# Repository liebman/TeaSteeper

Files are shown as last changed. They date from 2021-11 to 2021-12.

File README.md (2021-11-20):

# TeaSteeper

TeaSteeper is a simple device to prevent tea from being over steeped.

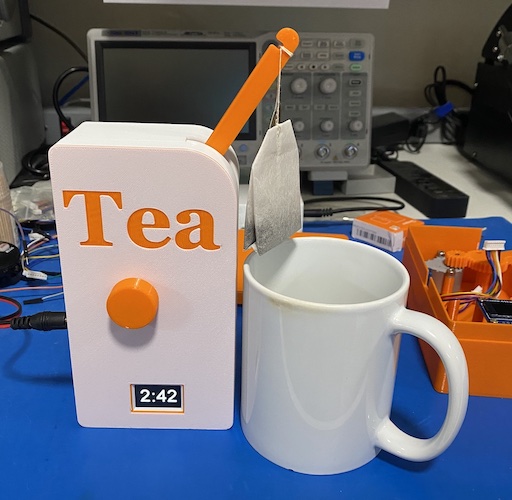
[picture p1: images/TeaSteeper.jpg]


- [src](src) contains firmware sources
- [kicad](kicad) contains [KiCad](https://www.kicad.org/) design files
- [enclosure](enclosure) contains [FreeCad](https://www.freecadweb.org/) and STL files for the enclosure.
These are designed for a FDM printer with a .4mm nozzle and .2mm layer height.

## Firmware

This project uses [PlatformIO](https://platformio.org/) to build firmware.

## Schematic

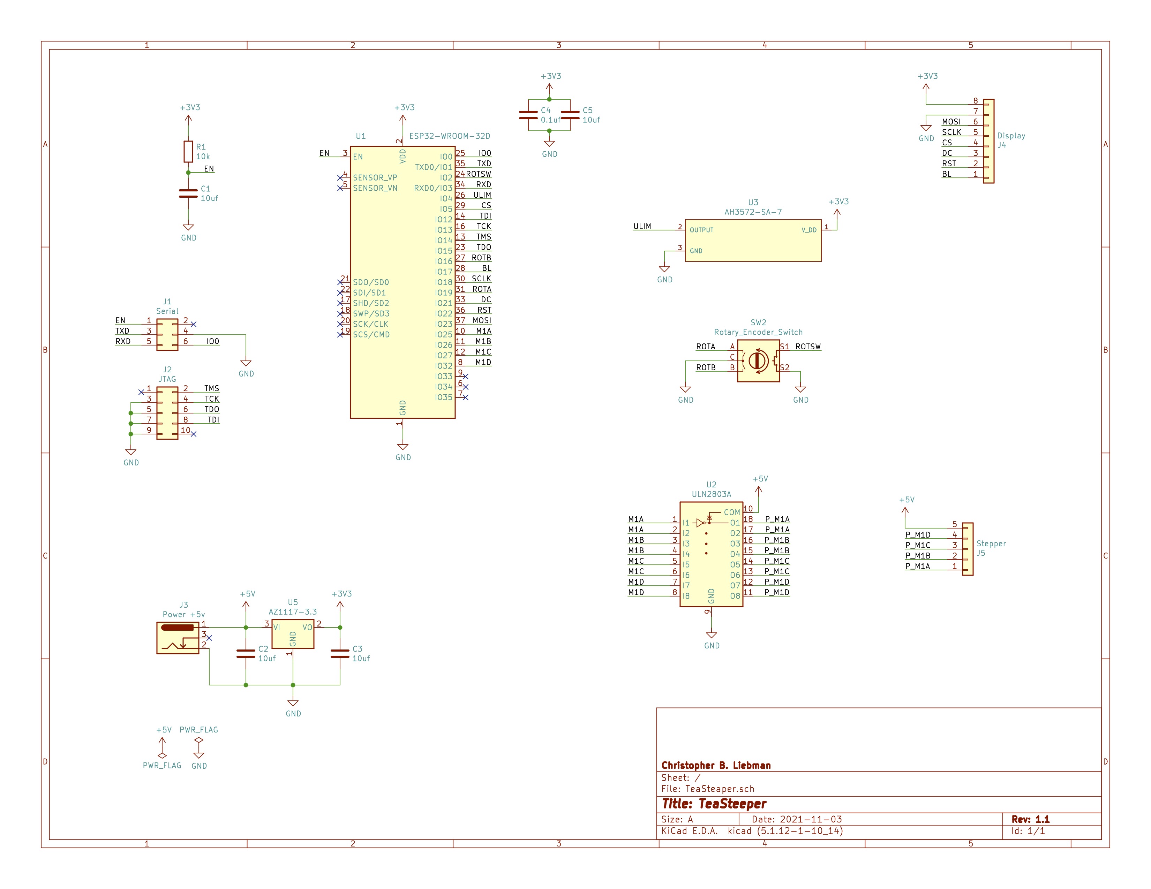
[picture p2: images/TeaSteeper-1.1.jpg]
Schematic


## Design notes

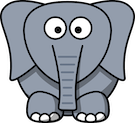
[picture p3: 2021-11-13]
src/elephant.png

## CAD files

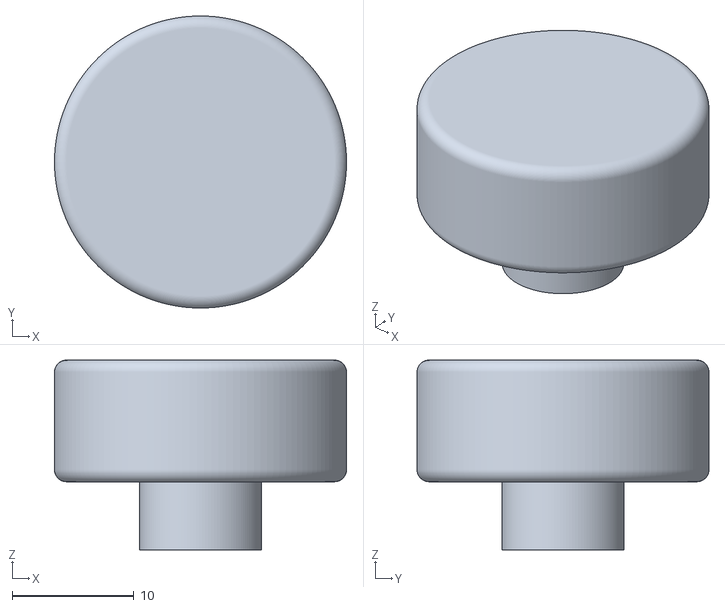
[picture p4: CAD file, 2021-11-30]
enclosure/assembly-AssemblyBody_knob.stl
24.0 x 24.0 x 15.6

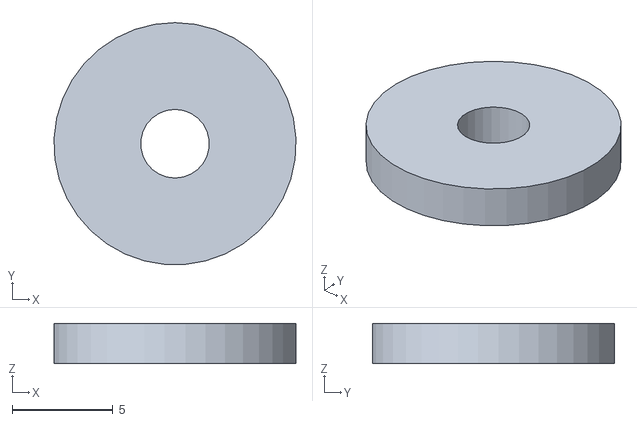
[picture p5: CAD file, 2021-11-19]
enclosure/assembly-AssemblyBody_gear02cap.stl
12.0 x 12.0 x 2.00

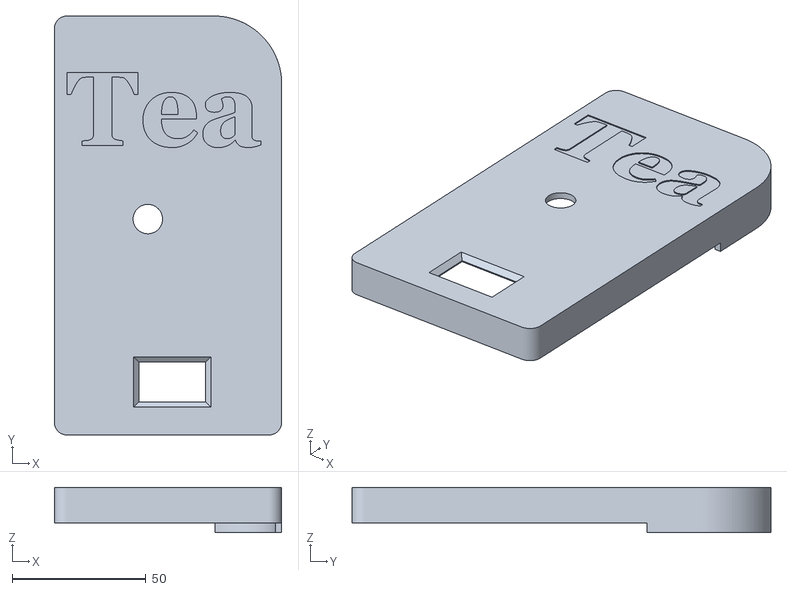
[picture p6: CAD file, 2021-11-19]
enclosure/assembly-AssemblyBody_front.stl
85.1 x 156.8 x 17.0

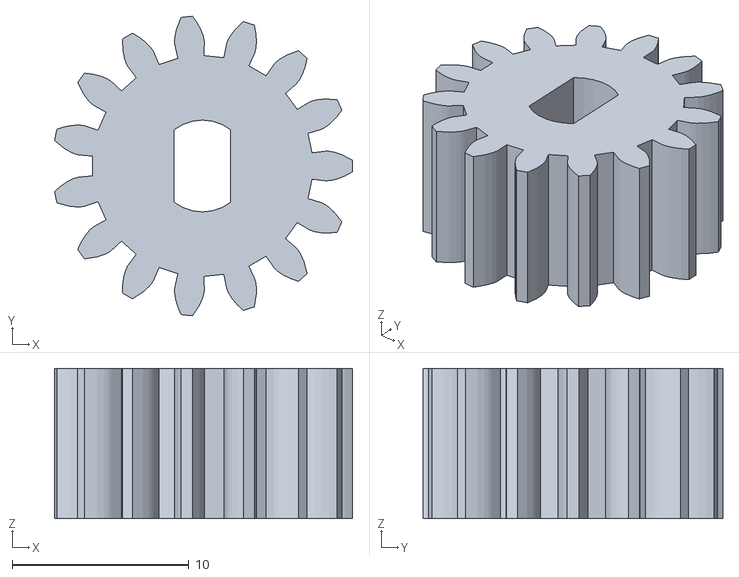
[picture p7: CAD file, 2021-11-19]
enclosure/assembly-AssemblyPart_gear01.stl
16.9 x 17.0 x 8.50

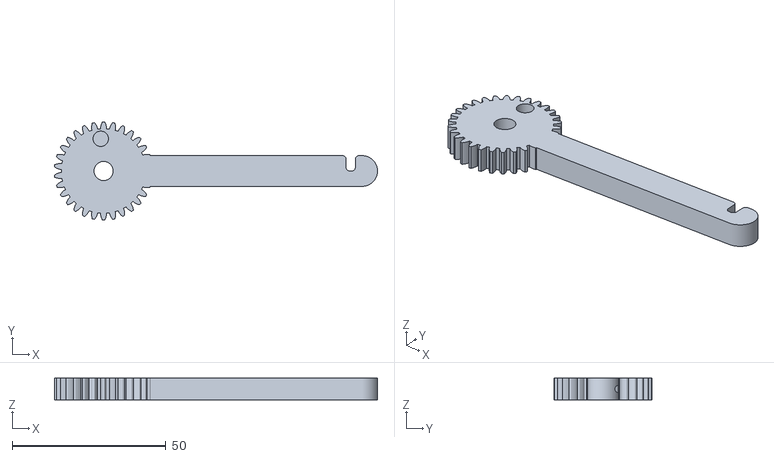
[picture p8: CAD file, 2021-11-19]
enclosure/assembly-AssemblyPart_gear02.stl
104.9 x 32.0 x 7.00

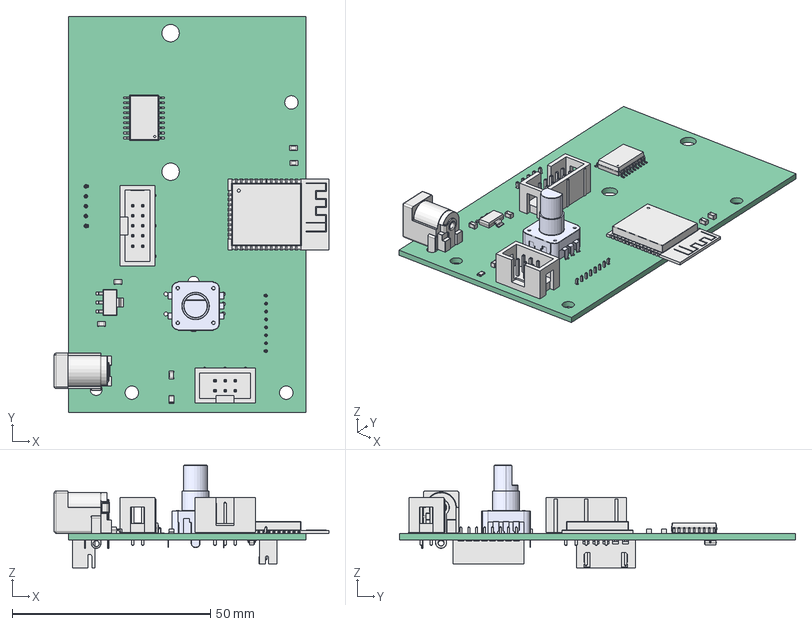
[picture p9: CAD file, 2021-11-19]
enclosure/PCB.FCStd
69.4 x 100.0 x 25.9 mm
Pcb_18fc
U1_ESP32-WROOM-32_6181740E
U5_SOT_223_61818112
U2_SOIC_18W_75x116mm_P127mm_6181850D
SW2_User Library-PEC12-4220F-S0024-1_61817C63
R1_R_0805_2012Metric_61817EAB
J3_BarrelJack_CUI_PJ-202A_Horizontal_7100000000.0 x 2
J2_IDC_Header_2x05_P254mm_Vertical_6181716A
J1_IDC_Header_2x03_P254mm_Vertical_61817595
C5_C_0805_2012Metric_61817AE0 x 5
J4_JST_B8B_PH_K_61817312
J5_JST_B5B_XH_A_61817515
U3_SOT_23_6181763C

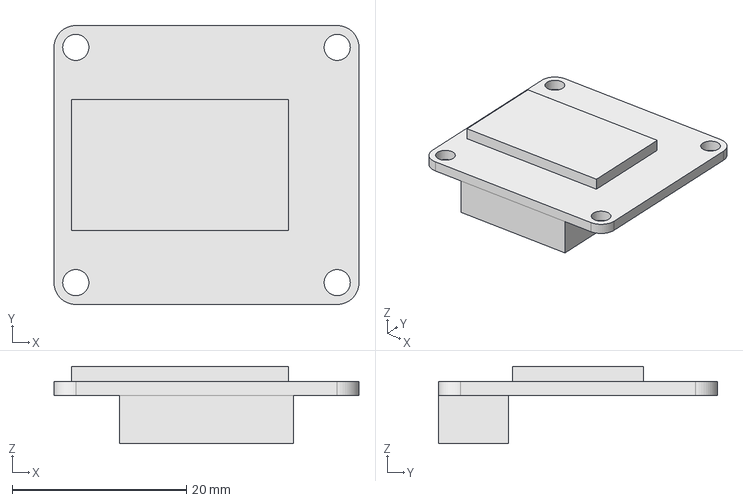
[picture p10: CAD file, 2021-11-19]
enclosure/LCD114.FCStd
35.0 x 32.0 x 8.85 mm

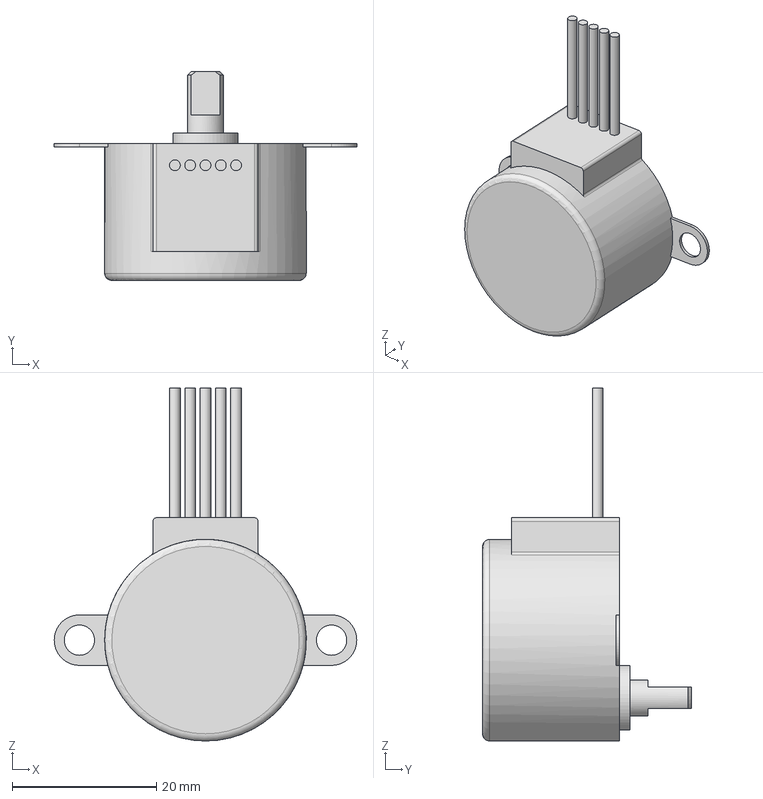
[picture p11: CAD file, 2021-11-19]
enclosure/Stepper28BYJ48.FCStd
42.0 x 29.0 x 49.0 mm

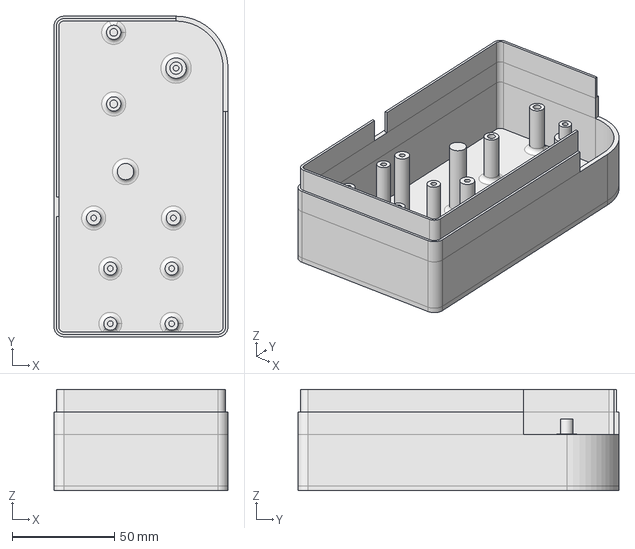
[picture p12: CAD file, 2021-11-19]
enclosure/Back.FCStd
85.1 x 156.8 x 49.6 mm

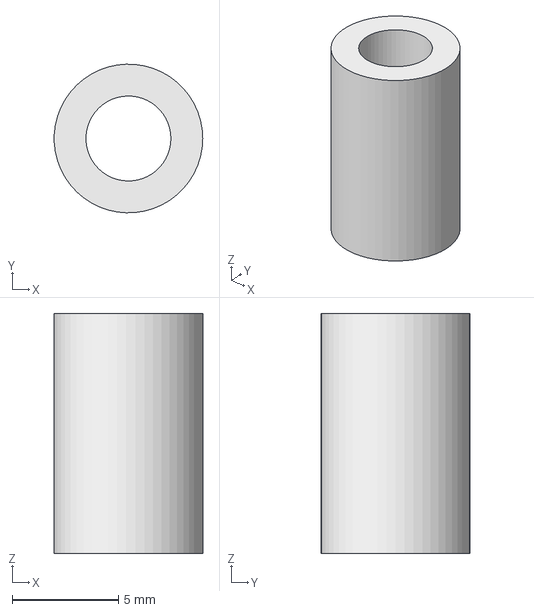
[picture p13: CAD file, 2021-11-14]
enclosure/SpacerStepper.FCStd
6.99 x 7.00 x 11.3 mm

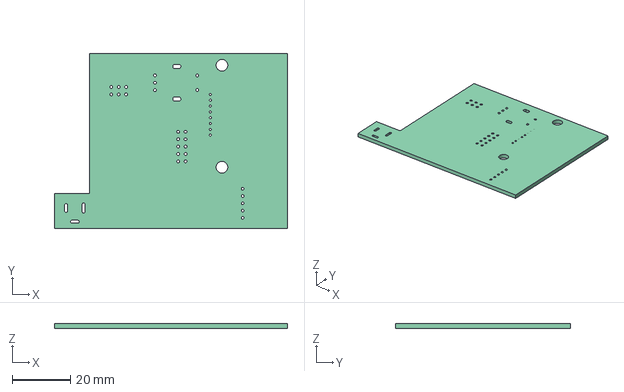
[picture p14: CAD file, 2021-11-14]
enclosure/PCB_outline.FCStd
80.0 x 60.0 x 1.60 mm

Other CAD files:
enclosure/assembly.FCStd
enclosure/knob.FCStd
enclosure/data.FCStd
enclosure/Gear02.FCStd
enclosure/Gear01.FCStd
enclosure/Gear02Cap.FCStd
enclosure/Front.FCStd

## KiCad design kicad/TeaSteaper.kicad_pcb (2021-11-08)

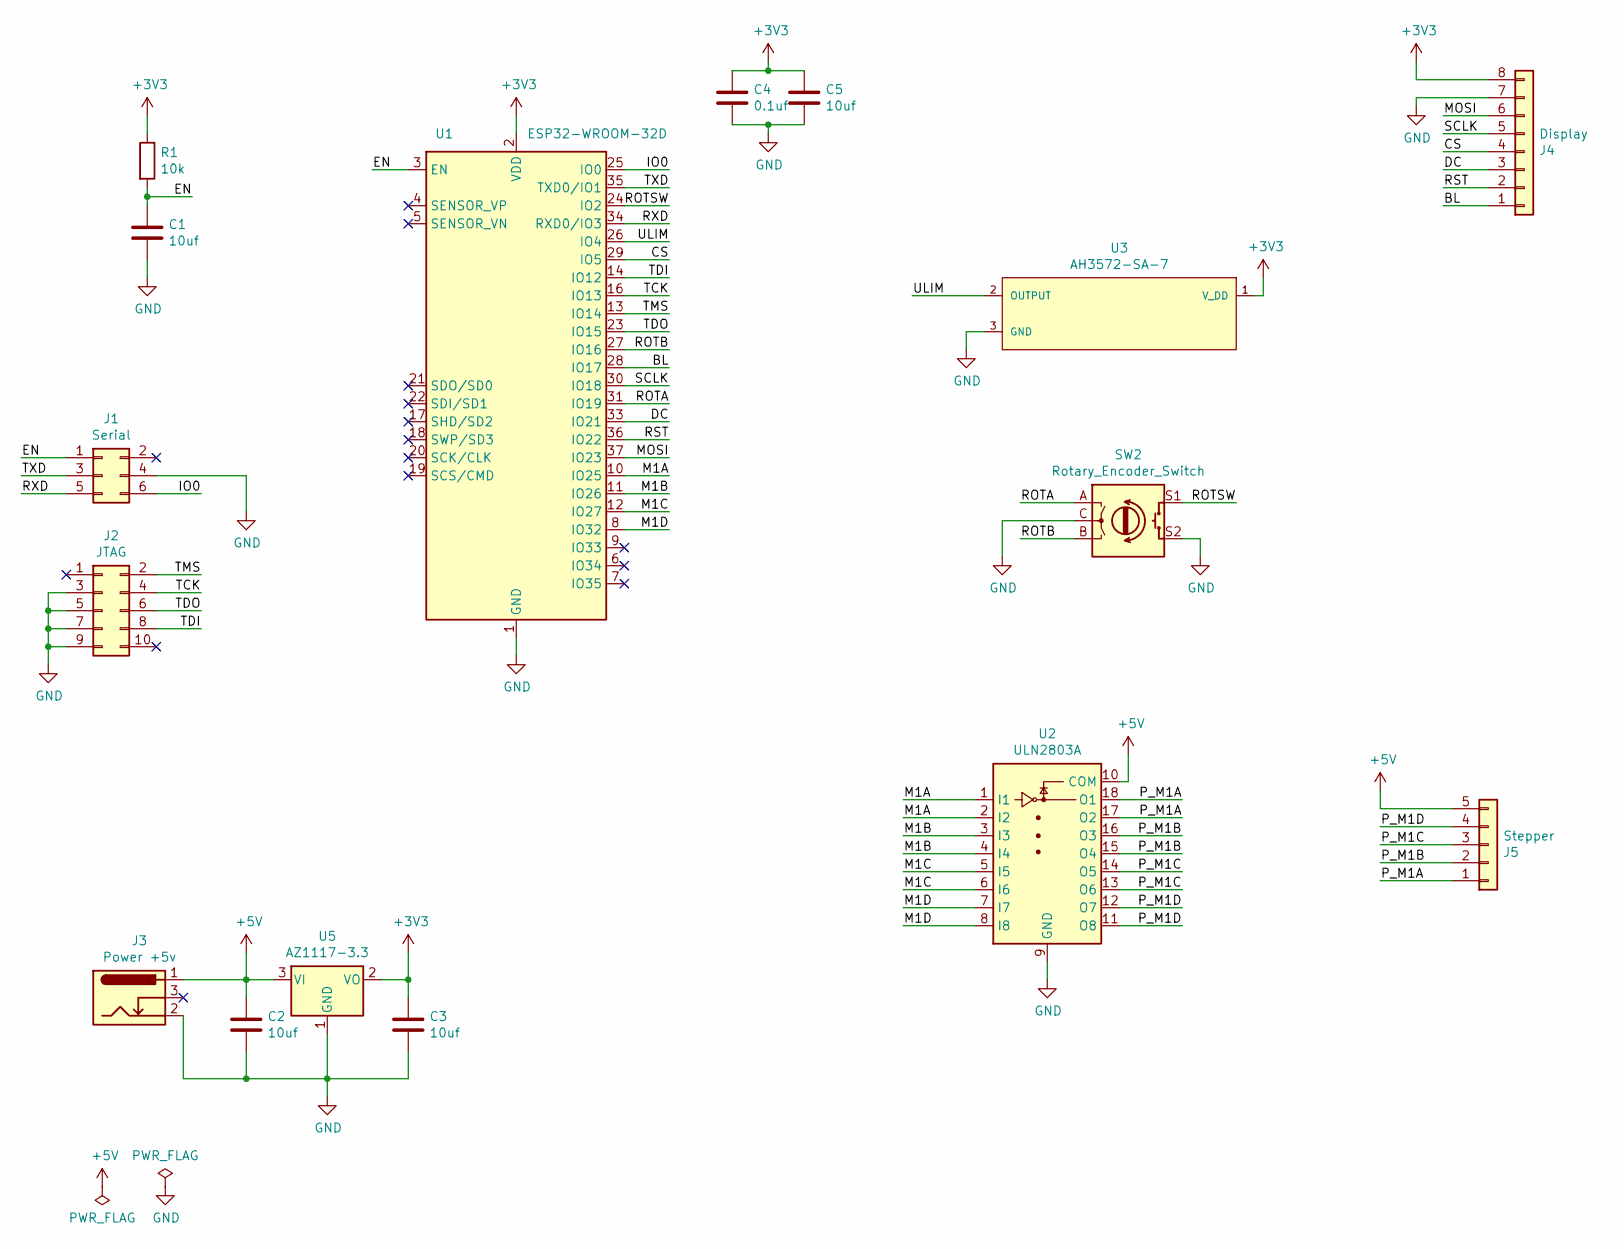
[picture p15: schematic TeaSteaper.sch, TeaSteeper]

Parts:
C1, C2, C3, C5: 10uf; C_0805_2012Metric_Pad1.18x1.45mm_HandSolder
C4: 0.1uf; C_0805_2012Metric_Pad1.18x1.45mm_HandSolder
J1: Serial; IDC-Header_2x03_P2.54mm_Vertical
J2: JTAG; IDC-Header_2x05_P2.54mm_Vertical
J3: Power +5v; BarrelJack_CUI_PJ-202A_Horizontal
J4: Display; JST_PH_B8B-PH-K_1x08_P2.00mm_Vertical
J5: Stepper; JST_XH_B5B-XH-A_1x05_P2.50mm_Vertical
R1: 10k; R_0805_2012Metric_Pad1.20x1.40mm_HandSolder
SW2: Rotary_Encoder_Switch; RotaryEncoder_Alps_EC11E-Switch_Vertical_H20mm
U1: ESP32-WROOM-32D; ESP32-WROOM-32
U2: ULN2803A; SOIC-18W_7.5x11.6mm_P1.27mm
U3: AH3572-SA-7; SOT-23; mouser part number 621-AH3572-SA-7; digikey description MAG SWITCH OMNIPOLAR SOT23 T&R
U5: AZ1117-3.3; SOT-223-3_TabPin2

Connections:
+3V3: C3.1, C4.1, C5.1, J4.8, R1.1, U1.2 (VDD), U3.1 (V_DD), U5.2 (VO)
+5V: C2.1, J3.1, J5.5, U2.10 (COM), U5.3 (VI)
/BL: J4.1, U1.28 (IO17)
/CS: J4.4, U1.29 (IO5)
/DC: J4.3, U1.33 (IO21)
/EN: C1.1, J1.1, R1.2, U1.3 (EN)
/IO0: J1.6, U1.25 (IO0)
/M1A: U1.10 (IO25), U2.1 (I1), U2.2 (I2)
/M1B: U1.11 (IO26), U2.3 (I3), U2.4 (I4)
/M1C: U1.12 (IO27), U2.5 (I5), U2.6 (I6)
/M1D: U1.8 (IO32), U2.7 (I7), U2.8 (I8)
/MOSI: J4.6, U1.37 (IO23)
/P_M1A: J5.1, U2.17 (O2), U2.18 (O1)
/P_M1B: J5.2, U2.15 (O4), U2.16 (O3)
/P_M1C: J5.3, U2.13 (O6), U2.14 (O5)
/P_M1D: J5.4, U2.11 (O8), U2.12 (O7)
/ROTA: SW2.A, U1.31 (IO19)
/ROTB: SW2.B, U1.27 (IO16)
/ROTSW: SW2.S1, U1.24 (IO2)
/RST: J4.2, U1.36 (IO22)
/RXD: J1.5, U1.34 (RXD0/IO3)
/SCLK: J4.5, U1.30 (IO18)
/TCK: J2.4, U1.16 (IO13)
/TDI: J2.8, U1.14 (IO12)
/TDO: J2.6, U1.23 (IO15)
/TMS: J2.2, U1.13 (IO14)
/TXD: J1.3, U1.35 (TXD0/IO1)
/ULIM: U1.26 (IO4), U3.2 (OUTPUT)
GND: C1.2, C2.2, C3.2, C4.2, C5.2, J1.4, J2.3, J2.5, J2.7, J2.9, J3.2, J4.7, SW2.C, SW2.S2, U1.1 (GND), U1.15 (GND), U1.38 (GND), U1.39 (GND), U2.9 (GND), U3.3 (GND), U5.1 (GND)

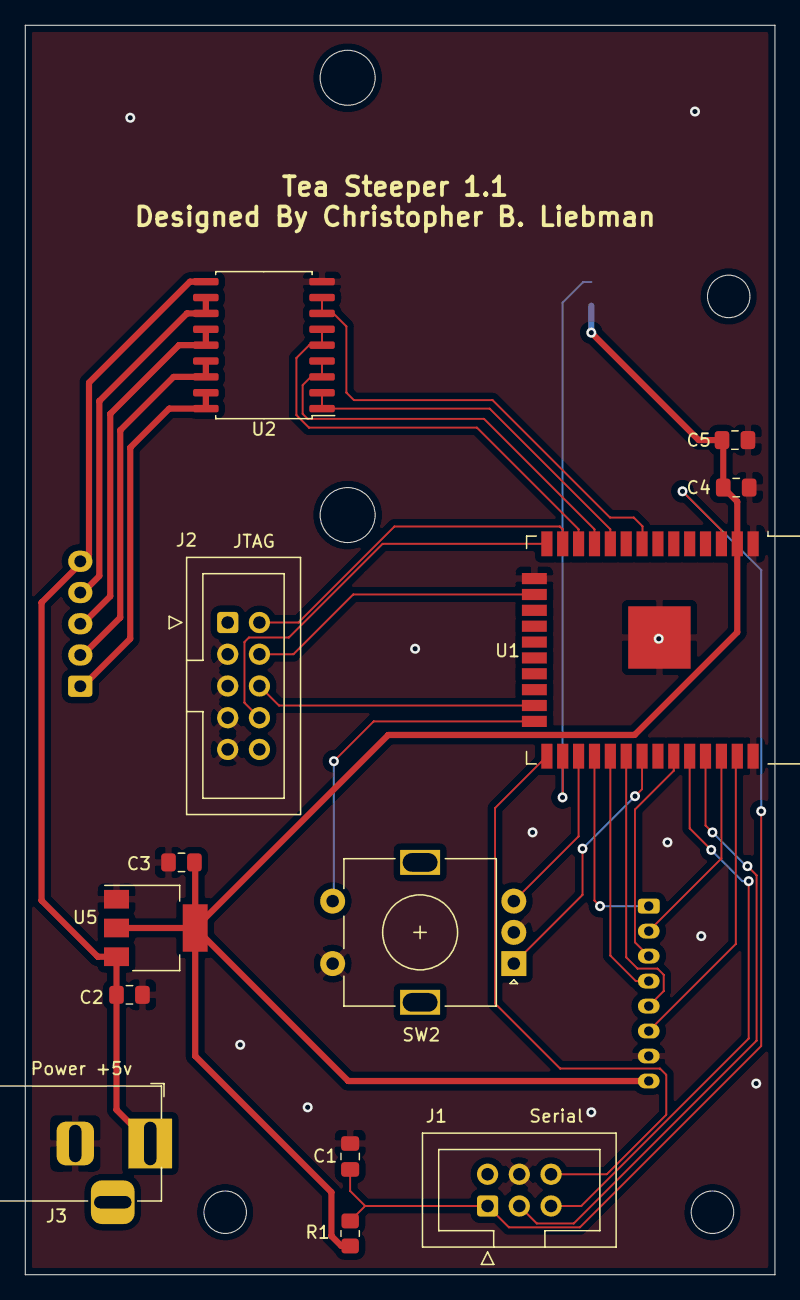
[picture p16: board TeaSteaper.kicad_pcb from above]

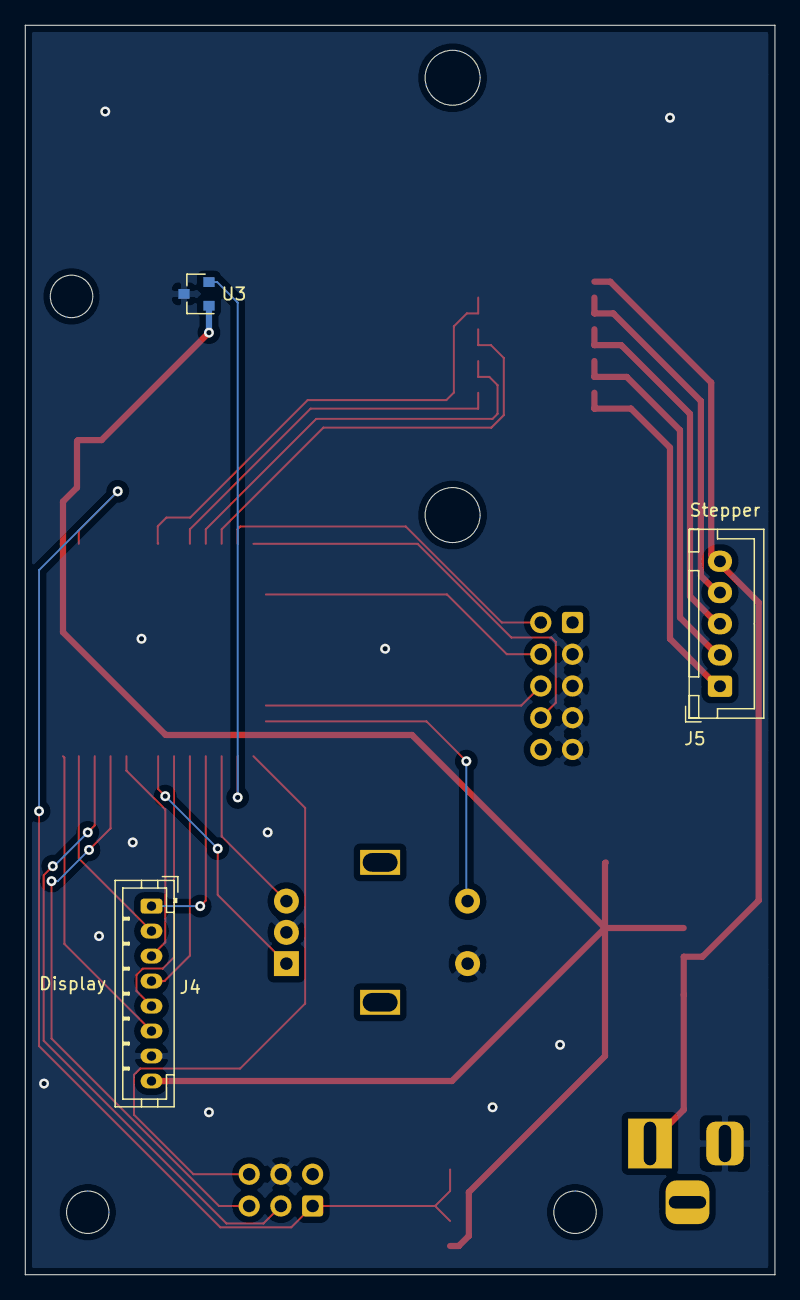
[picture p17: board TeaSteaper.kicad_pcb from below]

Board: 2 copper layers, 60.0 x 100.0 mm, 16 parts (3 on the bottom side), 29 nets.

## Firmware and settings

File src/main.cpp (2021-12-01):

/* 
 * MIT License
 *
 * Copyright (c) 2021 Christopher B. Liebman
 *
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
 * THE SOFTWARE IS PROVIDED "AS IS", WITHOUT WARRANTY OF ANY KIND, EXPRESS OR
 * IMPLIED, INCLUDING BUT NOT LIMITED TO THE WARRANTIES OF MERCHANTABILITY,
 * FITNESS FOR A PARTICULAR PURPOSE AND NONINFRINGEMENT. IN NO EVENT SHALL THE
 * AUTHORS OR COPYRIGHT HOLDERS BE LIABLE FOR ANY CLAIM, DAMAGES OR OTHER
 * LIABILITY, WHETHER IN AN ACTION OF CONTRACT, TORT OR OTHERWISE, ARISING FROM,
 * OUT OF OR IN CONNECTION WITH THE SOFTWARE OR THE USE OR OTHER DEALINGS IN THE
 * SOFTWARE.
 */

#include <Arduino.h>
#include <esp_sleep.h>
#include <SPI.h>
#include <TFT_eSPI.h>
#include "Log.h"
#include "DLogPrintWriter.h"
#include "UStepperGPIO.h"
#include "UStepper.h"
#include "EasyButton.h"
#include "RotaryEncoder.h"
#include "ConfigPortal.h"
#include "elephant.h"
#include "elephant_profile.h"
#include "version.h"

#ifndef STEEP_TIME
#define STEEP_TIME 150 // default steep time 2:30
#endif

#ifndef SCREEN_SAVER_TIME
#define SCREEN_SAVER_TIME 300
#endif

#ifndef SCREEN_BLANK_TIME
#define SCREEN_BLANK_TIME 600
#endif

#ifndef SPLASH_NAME
#define SPLASH_NAME "Someone Special"
#endif

#ifndef SPLASH_DATE
#define SPLASH_DATE "Christmas 2021"
#endif

extern void screensaverLife(TFT_eSPI* tft);

static const char* TAG = "main";
static const uint8_t PIN_ULIM = 4;
static const uint8_t PIN_M1A = 25;
static const uint8_t PIN_M1B = 26;
static const uint8_t PIN_M1C = 27;
static const uint8_t PIN_M1D = 32;
static const uint8_t PIN_ROTSW = 2;
static const uint8_t PIN_ROTA  = 19;
static const uint8_t PIN_ROTB  = 16;

DLog& dlog = DLog::getLog();

static UStepperGPIO io(PIN_M1A, PIN_M1B, PIN_M1C, PIN_M1D, PIN_ULIM);
static UStepper m(io);
static EasyButton button(PIN_ROTSW);
static RotaryEncoder *encoder;
static TFT_eSPI tft;
static ConfigPortal cp;

static const uint16_t elephant_step = 5;
static uint16_t       elephant_walking_buffer_sz = max(elephant_profile_width, elephant_profile_height) + 2*elephant_step;
static TFT_eSprite    elephant_walking(&tft);
static TFT_eSprite    elephant_walking_buffer(&tft);
static TFT_eSprite    elephant_looking(&tft);
static int16_t        easter_x;
static uint32_t       easter_look;

enum class State {
  IDLE,
  STARTING,
  STEEPING,
  STOPPING,
  SAVER,
  SPLASH,
  EASTER,
  BLANK,
  CONFIG
};

static volatile State    state        = State::SPLASH;
static volatile time_t   state_time   = 0;
static volatile uint32_t steep_time   = STEEP_TIME;
static volatile bool     clear_screen = false;
static volatile bool     syncing      = true;
static volatile bool     stopping     = false;

void logUptimeFirst(DLogBuffer& buffer, DLogLevel level)
{
    (void)level; // not used
    uint32_t now = millis();
    float seconds = (now % 60000L) / 1000.0;
    uint32_t days = now / 86400000;
    now -= days * 86400000;
    uint32_t hours = now / 3600000;
    now -= hours * 3600000;
    uint32_t minutes = now / 60000;
    buffer.printf("%03dd%02dh%02dm%02.3f ", days, hours, minutes, seconds);
}

static const char* stateName(State s)
{
  switch (s)
  {
    case State::IDLE:     return "IDLE";
    case State::STARTING: return "STARTING";
    case State::STEEPING: return "STEEPING";
    case State::STOPPING: return "STOPPING";
    case State::SAVER:    return "SAVER";
    case State::SPLASH:   return "SPLASH";
    case State::EASTER:   return "EASTER";
    case State::CONFIG:   return "CONFIG";
    case State::BLANK:    return "BLANK";
    default:              return "UNKNOWN";
  }
}

static void setState(State s, bool clear = false)
{
  dlog.info(TAG, "setState: %s -> %s", stateName(state), stateName(s));
  state = s;
  state_time = time(nullptr);
  if (clear)
  {
    clear_screen = true;
  }
}

static void startSteep(bool clean_screen = false)
{
  dlog.info(TAG, "startSteep");
  setState(State::STARTING, clean_screen);
  m.step(UStepper::FORWARD, 200, nullptr, [](){
    if (state == State::STARTING)
    {
      m.off(nullptr, 1000);
      setState(State::STEEPING);
    }
  }, 1000);
}

static void displayTime(uint32_t value, uint16_t color)
{
  char buf[8];
  uint8_t minutes = value / 60;
  uint8_t seconds = value % 60;
  tft.setTextColor(color, TFT_BLACK);
  tft.setTextFont(8);
  snprintf(buf, sizeof(buf)-1, "%01d:%02d", minutes, seconds);
  int16_t tw = tft.textWidth(buf);
  int32_t x = (TFT_HEIGHT - tw) / 2;
  int32_t y = (TFT_WIDTH - 75) / 2;
  tft.drawString(buf, x, y);
}

static void displaySplash()
{
  uint16_t green  = tft.color565(0, 255, 0);
  uint16_t orange = tft.color565(255, 165, 0);

  tft.setCursor(0, 2, 4);
  tft.setTextColor(green, TFT_BLACK);
  tft.println("TeaSteeper");
  tft.setTextFont(2);
  tft.setTextColor(TFT_WHITE, TFT_BLACK);
  tft.println(BUILD_VERSION);
  tft.println();
  tft.print("For ");
  tft.setTextColor(orange, TFT_BLACK);
  tft.println(SPLASH_NAME);
  tft.setTextColor(TFT_WHITE, TFT_BLACK);
  tft.println(SPLASH_DATE);
}

static void displayConfig()
{
  tft.setTextColor(TFT_WHITE, TFT_BLACK);
  tft.setCursor(0, 2, 4);
  tft.println("Config Active");
  tft.setTextFont(2);
  tft.println(BUILD_VERSION);
  tft.setTextFont(4);
  tft.setTextColor(tft.color565(0, 255, 0), TFT_BLACK);
  tft.println("SSID: TeaSteeper");
}

static void startEaster()
{
  easter_x    = 0;
  easter_look = 0;
  setState(State::EASTER, true);
}

static void displayEaster()
{
  if (easter_look != 0)
  {
    if (millis()-easter_look > 2000)
    {
      easter_look = 0;
      startSteep(true);
      return;
    }
    easter_x = TFT_HEIGHT-elephant_width;
    elephant_looking.pushSprite(easter_x, 0);
    return;
  }

  int16_t y = (TFT_WIDTH-elephant_walking_buffer_sz)/2;
  int16_t tilt = (easter_x/elephant_step)&1 ? 5 : -5;
  elephant_walking_buffer.fillSprite(TFT_BLACK);
  elephant_walking.pushRotated(&elephant_walking_buffer, tilt);
  elephant_walking_buffer.pushSprite(easter_x-elephant_profile_width, y);
  easter_x += elephant_step;
  if (easter_x > TFT_HEIGHT+elephant_profile_width/2)
  {
    easter_x = 0;
    easter_look = millis();
  }
  delay(90);
}

static void displayTask(void* data)
{
  (void)data;
  time_t last_update = 0;
  dlog.info(TAG, "displayTask");
  while(true)
  {
    if (clear_screen)
    {
      clear_screen = false;
      tft.fillScreen(TFT_BLACK);
      dlog.info(TAG, "displayTask: cleared screen!");
    }

    switch (state)
    {
      case State::IDLE:
        displayTime(steep_time, TFT_WHITE);
        break;
      case State::STARTING:
        displayTime(steep_time, tft.color565(255, 165, 0));
        break;
      case State::STEEPING:
      {
        time_t now = time(nullptr);
        uint32_t time_left = steep_time - (now - state_time);
        displayTime(time_left, tft.color565(0, 255, 0));
        break;
      }
      case State::STOPPING:
        displayTime(0, tft.color565(255, 165, 0));
        break;
      case State::SAVER:
        screensaverLife(&tft);
        break;
      case State::SPLASH:
        displaySplash();
        break;
      case State::EASTER:
        displayEaster();
        break;

      case State::CONFIG:
        displayConfig();
        break;
    }
    delay(10);
  }
}

static void displayInit()
{
  dlog.info(TAG, "displayInit");
  //Set up the display
  tft.init();
  tft.setRotation(3);
  tft.fillScreen(TFT_BLACK);
  tft.setTextSize(1);
  tft.setTextColor(TFT_WHITE);
  tft.setCursor(0, 0);
  dlog.info(TAG, "displayInit: create display task");
  xTaskCreatePinnedToCore(displayTask, "display", 4096, nullptr, 1, nullptr, 1);
}

void setup()
{
  Serial.begin(115200);
  dlog.begin(new DLogPrintWriter(Serial));
  dlog.setPreFunc(&logUptimeFirst);
  delay(200);
  dlog.info(TAG, "setup: Starting!");

  displayInit();

  // initialize sprites
  dlog.info(TAG, "setup: initialize sprites");
  elephant_looking.createSprite(elephant_width, elephant_height);
  elephant_looking.setSwapBytes(true);
  elephant_looking.pushImage(0, 0, elephant_width, elephant_height, elephant);
  elephant_walking.setPivot(elephant_width/2, elephant_height/2);

  elephant_walking.createSprite(elephant_width, elephant_height);
  elephant_walking.setSwapBytes(true);
  elephant_walking.pushImage(0, 0, elephant_profile_width, elephant_profile_height, elephant_profile);
  elephant_walking.setPivot(elephant_profile_width/2, elephant_profile_height/2);

  elephant_walking_buffer.createSprite(elephant_walking_buffer_sz, elephant_walking_buffer_sz);
  elephant_walking_buffer.setPivot(elephant_walking_buffer_sz/2, elephant_walking_buffer_sz/2);


  dlog.info(TAG, "setup: initialze button and encoder");
  button.begin();
  encoder = new RotaryEncoder(PIN_ROTB, PIN_ROTA, RotaryEncoder::LatchMode::FOUR3);
  encoder->setPosition(steep_time);

  dlog.info(TAG, "setup: io begin");
  io.begin();
  dlog.info(TAG, "setup: m begin");
  m.begin();
  dlog.info(TAG, "setup: sync begin");
  m.sync(nullptr, [](){
    dlog.info(TAG, "m.sync done!");
    syncing = false;
    }, 1000);
  // wait for sync to be done.
  while(syncing)
  {
    delay(100);
  }
  dlog.info(TAG, "setup: limit=%s", io.isUpperLimit() ? "true" : "false");
  m.off([](){
    dlog.info(TAG, "m.off done!");
  }, 1000);
  delay(2000); // make sure the splash screen is visable for a few seconds
  bool start_config = digitalRead(PIN_ROTSW) == 0;
  if (start_config)
  {
    cp.startPortal("TeaSteeper");
  }
  setState(start_config ? State::CONFIG : State::IDLE, true);
  dlog.info(TAG, "setup: done");
}

void loop()
{
  cp.poll();
  button.read();

  time_t now = time(nullptr);

  // tick the encoder except when we are in SAVER, BLANK, or EASTER states
  if (state != State::SAVER && state != State::BLANK && state != State::EASTER)
  {
    encoder->tick();

    long pos = encoder->getPosition();
    if (pos < 0)
    {
      pos = 0;
      encoder->setPosition(pos);
    } else if (pos > 599)
    {
      pos = 599;
      encoder->setPosition(pos);
    }

    if (pos != steep_time)
    {
      steep_time = pos;
    }
  }

  if (button.pressedFor(5000) && state != State::BLANK)
  {
    dlog.info(TAG, "loop: RESETTING!!!!!!");
    delay(100);
    ESP.restart();
  }

  switch(state)
  {
    case State::IDLE:
    {
      // detect that arm was pushed off home position and correct.
      if (!io.isUpperLimit())
      {
        dlog.info(TAG, "loop: arm was physically moved, correcting!");
        setState(State::STOPPING);
        m.step(UStepper::FORWARD, 50, nullptr, [](){
          m.step(UStepper::REVERSE, 500, nullptr, [](){
            dlog.info(TAG, "loop: state now IDLE");
            m.off(nullptr, 1000);
            setState(State::IDLE);
          }, 1000);
        }, 1000);
      }
      if (button.wasReleased())
      {
        if (steep_time % 60 == 42)
        {
          dlog.info(TAG, "loop: 42! starting easter egg!");
          startEaster();
          break;
        }
        startSteep();
      }
      else
      {
        // screen saver starts after some amount of idle time
        if ((now - state_time) > SCREEN_SAVER_TIME)
        {
          dlog.info(TAG, "loop: idle! starting screensaver!");
          setState(State::SAVER, true);
          break;
        }
      }
      break;
    }
    case State::STARTING:
    case State::STEEPING:
    {
      uint32_t time_left = steep_time - (now - state_time);
      if (button.wasPressed() || time_left<1)
      {
        dlog.info(TAG, "loop: state now STOPPING");
        setState(State::STOPPING);
        m.step(UStepper::REVERSE, 500, nullptr, [](){
          dlog.info(TAG, "loop: state now IDLE");
          m.off(nullptr, 1000);
          setState(State::IDLE);
        }, 1000);
      }
      break;
    }
    case State::STOPPING:
      break;
    case State::EASTER:
      if (button.wasReleased())
      {
        dlog.info(TAG, "loop: stop EASTER");
        setState(State::IDLE, true);
      }
      break;
    case State::BLANK:
      if (button.wasReleased()) // was seen pressed and released
      {
        dlog.info(TAG, "loop: stop BLANK");
        setState(State::IDLE, false);
        dlog.info(TAG, "loop: turning on backlight");
        digitalWrite(TFT_BL, HIGH);
      }
      else if (button.isReleased()) // is currently released
      {
        dlog.debug(TAG, "loop: start light sleep!");
        delay(100);
        esp_sleep_enable_timer_wakeup(10000000); // sleep 10 seconds at a time
        esp_sleep_enable_ext0_wakeup((gpio_num_t)PIN_ROTSW, 0);
        esp_light_sleep_start();
        dlog.debug(TAG, "loop: wakeup from light sleep!");
      }
      break;

    case State::SAVER:
      if (button.wasReleased())
      {
        dlog.info(TAG, "loop: stop SAVER");
        setState(State::IDLE, true);
      }
      // screen blank starts after 5 minutes in saver
      if ((now - state_time) > SCREEN_BLANK_TIME)
      {
        dlog.info(TAG, "loop: idle! starting blank!");
        digitalWrite(TFT_BL, LOW);
        setState(State::BLANK, true);
        dlog.info(TAG, "loop: waiting for screen to be cleared");
        while(clear_screen)
        {
          delay(1);
        }
        delay(40);
      }
      break;
  }

  delay(1);
}

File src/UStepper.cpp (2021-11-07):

/* 
 * MIT License
 *
 * Copyright (c) 2021 Christopher B. Liebman
 *
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
 * THE SOFTWARE IS PROVIDED "AS IS", WITHOUT WARRANTY OF ANY KIND, EXPRESS OR
 * IMPLIED, INCLUDING BUT NOT LIMITED TO THE WARRANTIES OF MERCHANTABILITY,
 * FITNESS FOR A PARTICULAR PURPOSE AND NONINFRINGEMENT. IN NO EVENT SHALL THE
 * AUTHORS OR COPYRIGHT HOLDERS BE LIABLE FOR ANY CLAIM, DAMAGES OR OTHER
 * LIABILITY, WHETHER IN AN ACTION OF CONTRACT, TORT OR OTHERWISE, ARISING FROM,
 * OUT OF OR IN CONNECTION WITH THE SOFTWARE OR THE USE OR OTHER DEALINGS IN THE
 * SOFTWARE.
 */

#include "UStepper.h"
#include "Log.h"

static const char* TAG = "UStepper";

#ifndef USTEPPER_TASK_PRI
#define USTEPPER_TASK_PRI 3
#endif

#ifndef USTEPPER_TASK_CORE
#define USTEPPER_TASK_CORE ARDUINO_RUNNING_CORE
#endif

static uint8_t half_steps[8] = {
    0b0001, // { LOW,  LOW,  LOW,  HIGH }, // 0
    0b0011, // { LOW,  LOW,  HIGH, HIGH }, // 1
    0b0010, // { LOW,  LOW,  HIGH, LOW  }, // 2
    0b0110, // { LOW,  HIGH, HIGH, LOW  }, // 3
    0b0100, // { LOW,  HIGH, LOW,  LOW  }, // 4
    0b1100, // { HIGH, HIGH, LOW,  LOW  }, // 5
    0b1000, // { HIGH, LOW,  LOW,  LOW  }, // 6
    0b1001  // { HIGH, LOW,  LOW,  HIGH }, // 7
};

static uint8_t full_steps[8] = {
    0b1001, // { HIGH, LOW,  LOW,  HIGH }, // 3
    0b0011, // { LOW,  LOW,  HIGH, HIGH }, // 2
    0b0110, // { LOW,  HIGH, HIGH, LOW  }, // 1
    0b1100, // { HIGH, HIGH, LOW,  LOW  }, // 0
};

static void taskStart(void* data)
{
    UStepper* stepper = (UStepper*)data;
    stepper->task();
}

UStepper::UStepper(UStepperIO& gpio, StepType step_type, uint32_t step_delay)
: _gpio(gpio),
  _step_type(step_type),
  _step_delay(step_delay),
  _extent(DEFAULT_EXTENT)
{
}

UStepper::~UStepper()
{
}

bool UStepper::begin(const char* name)
{
    _command_queue = xQueueCreate(1, sizeof(CommandMessage));
    if (_command_queue == 0)
    {
        return false;
    }
    xTaskCreatePinnedToCore(&taskStart, name, 4096, this, 2, &_task, 1);
    if (_task == 0)
    {
        return false;
    }
    return true;
}

uint16_t UStepper::getPosition()
{
    return _position;
}

float_t UStepper::getPercent()
{
    return (float_t)_position / (float_t)_extent;
}

bool UStepper::step(Direction direction, uint32_t steps, ustepper_progress_t progress, ustepper_finished_t finished, uint32_t wait_ms)
{
    CommandMessage cmd;
    cmd.command     = Command::STEP;
    cmd.direction   = direction;
    cmd.value.steps = steps;
    cmd.progress    = progress;
    cmd.finished    = finished;
    return queueCommand(&cmd, wait_ms);
}

bool UStepper::percent(float_t percent, ustepper_progress_t progress, ustepper_finished_t finished, uint32_t wait_ms)
{
    if (_extent == 0)
    {
        Serial.printf("UStepper::percent: FAILING!  sync not done!\n");
        return false;
    }
    uint16_t pos = (uint16_t)(_extent * percent + 0.5);
    return position(pos, progress, finished, wait_ms);
}

bool UStepper::position(uint16_t position, ustepper_progress_t progress, ustepper_finished_t finished, uint32_t wait_ms)
{
    CommandMessage cmd;
    cmd.command        = Command::POSITION;
    cmd.value.position = position;
    cmd.progress       = progress;
    cmd.finished       = finished;
    return queueCommand(&cmd, wait_ms);
}

bool UStepper::sync(ustepper_progress_t progress, ustepper_finished_t finished, uint32_t wait_ms)
{
    CommandMessage cmd;
    cmd.command        = Command::SYNC;
    cmd.progress       = progress;
    cmd.finished       = finished;
    return queueCommand(&cmd, wait_ms);
}

bool UStepper::off(ustepper_finished_t finished, uint32_t wait_ms)
{
    CommandMessage cmd;
    cmd.command        = Command::OFF;
    cmd.progress       = nullptr;
    cmd.finished       = finished;
    return queueCommand(&cmd, wait_ms);
}

bool UStepper::queueCommand(CommandMessage* message, uint32_t wait_ms)
{
    if (xQueueSendToBack(_command_queue, message, pdMS_TO_TICKS(wait_ms)) != pdTRUE)
    {
        return false;
    }
    return true;
}

void UStepper::onStep(ustepper_step_t on_step)
{
    _on_step.push_back(on_step);
}

void UStepper::task()
{
    CommandMessage message;
    while(true)
    {
        if (xQueueReceive(_command_queue, &message, pdMS_TO_TICKS(100)))
        {
            process(message);
        }
    }
}

void UStepper::process(CommandMessage& message)
{
    _active = true;

    switch (message.command)
    {
    case Command::STEP:
        cmdStep(message.direction, message.value.steps, message.progress);
        break;

    case Command::POSITION:
        cmdPosition(message.value.position, message.progress);
        break;

    case Command::SYNC:
        cmdSync(message.progress);
        break;

    case Command::OFF:
        _gpio.off();
        break;

    default:
        Serial.printf("UStepper::process: unknown command:0x%d\n", (int)message.command);
        break;
    }

    _active = false;

    if(message.finished)
    {
        message.finished();
    }
}

void UStepper::cmdSync(ustepper_progress_t progress)
{
    Serial.printf("UStepper::cmdSync: starting!\n");
    //
    // if we are at teh reverse limit then step away
    //
    if (_gpio.isUpperLimit())
    {
        for(uint8_t attempt = 1; attempt <= 5; ++attempt)
        {
            dlog.info(TAG, "::cmdSync: at limit, stepping FORWARD a bit (attempt=%u)", attempt);
            cmdStep(FORWARD, 50, progress);
            if (!_gpio.isUpperLimit())
            {
                break;
            }
        }
        if (_gpio.isUpperLimit())
        {
            dlog.error(TAG, "::cmdSync: failed to move away from limit!");
            return;
        }
    }

    //
    // find the reverse limit
    //
    dlog.info(TAG, "::cmdSync: now REVERSING to find the limit");
    cmdStep(REVERSE,  MAX_STEPS, progress);
    if (!_gpio.isUpperLimit())
    {
        dlog.error(TAG, "UStepper::cmdSync: failed to find REVERSE limit!");
        return;
    }
    _position = 0;
}

void UStepper::cmdPosition(uint16_t position, ustepper_progress_t progress)
{
    int16_t delta = position - _position;
    uint16_t steps = abs(delta);
    Direction direction = delta < 0 ? REVERSE : FORWARD;
    cmdStep(direction, steps, progress);
}
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

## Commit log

2021-10-26 1st board layout (changing so want to save this)
    [TeaSteaper.kicad_pcb, TeaSteaper.sch]
2021-10-28 board v1.0 ordered
    [TeaSteaper.kicad_pcb, TeaSteaper.sch]
2021-11-06 switch to smaller waveshare 1.14" display
2021-11-06 board v1.1
    [TeaSteaper.kicad_pcb, TeaSteaper.sch]
2021-11-07 detect manual shifting of tea arm while idle
2021-11-07 Added firmware update/version/splash screen/long press reset
    [main.cpp]
2021-11-07 added copyright to some files where it was missing
    [UStepper.cpp, UStepper.h, UStepperGPIO.cpp]
2021-11-07 fix minor issue when canceling screen saver
    [main.cpp]
2021-11-08 added a few dimentions to help enclosure fitting
    [TeaSteaper.kicad_pcb]
2021-11-14 added enclosure draft
    [Back.FCStd, Body_back.stl, Body_front.stl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]
2021-11-14 adjust stepper mount thickness t fix spacer length
    [Back.FCStd, Gear01.FCStd, Gear02.FCStd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]
2021-11-19 small tweaks to enclosure
    [Back.FCStd, Body_back.stl, Body_front.stl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]
2021-11-28 improve wakeup a bit, still need a timer.
2021-11-28 improve wakeup added timer
2021-11-30 adjust knob shaft diameter for improved fit.
    [assembly-AssemblyBody_knob.stl, data.FCStd, knob.FCStd]
2021-12-01 cut the log noise from sleep start/end
    [main.cpp]
2021-12-03 move to arduino-esp32 2.0.1
